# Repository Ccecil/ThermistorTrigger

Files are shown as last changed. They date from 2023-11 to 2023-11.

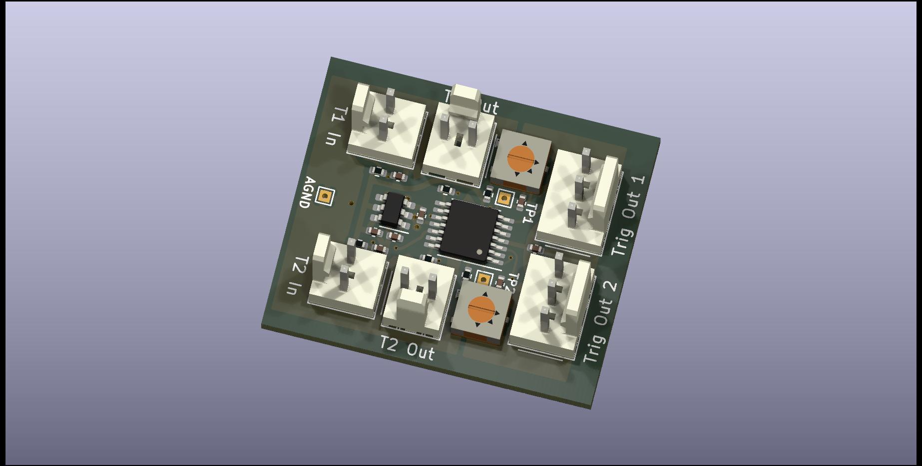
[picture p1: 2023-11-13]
ThermistorComparator.jpg

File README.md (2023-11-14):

# ThermistorTrigger

ThermistorComparator

Setpoint trigger designed to be a hardware failsafe for thermistor based temperature readings

This is designed to be a trigger board that can trigger other devices in the event of an overtemperature.  

Simply plug a standard thermistor into either input then the signal is buffered by an opamp and stabilized.  From there you can take the signal out and send it to your main control board as a temp sensor but it also drives into another opamp setpoint trigger which is set by the onboard potentiometer.  This allows you to set a trigger point in hardware that will drive the digital output of the setpoint trigger low if it exceeds the desired temp.

This is intended to go along with a couple of my other projects (Flambehub and Flambegate which are the devices which will kill the power in a "dumb" way requiring no MCU intervention) but this can also be used on a device such as a 3d printer (or other CNC device) to trigger a halt on the MCU if it is attached to the control board.

Available at: https://www.robosprout.com/product/thermistortrigger/

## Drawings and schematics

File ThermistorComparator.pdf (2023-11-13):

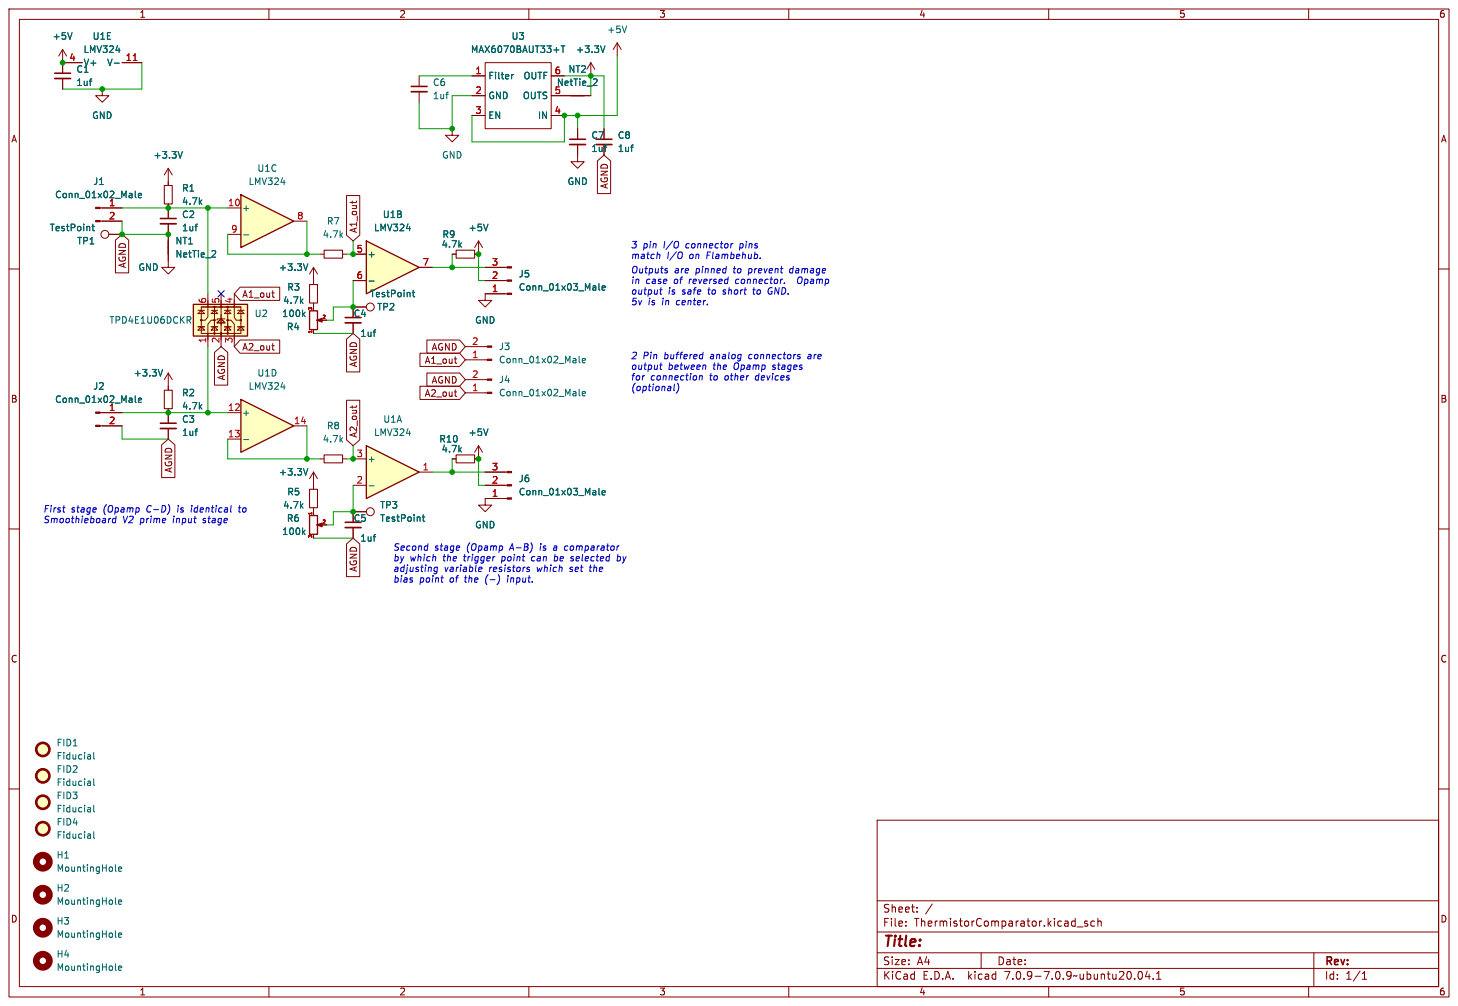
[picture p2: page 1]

output between the Opamp stages

FID3 Fiducial H1 MountingHole H2 MountingHole H4 MountingHole FID1 Fiducial

Id: 1/1 Title: File: ThermistorComparator.kicad_sch Sheet: / FID2 Fiducial

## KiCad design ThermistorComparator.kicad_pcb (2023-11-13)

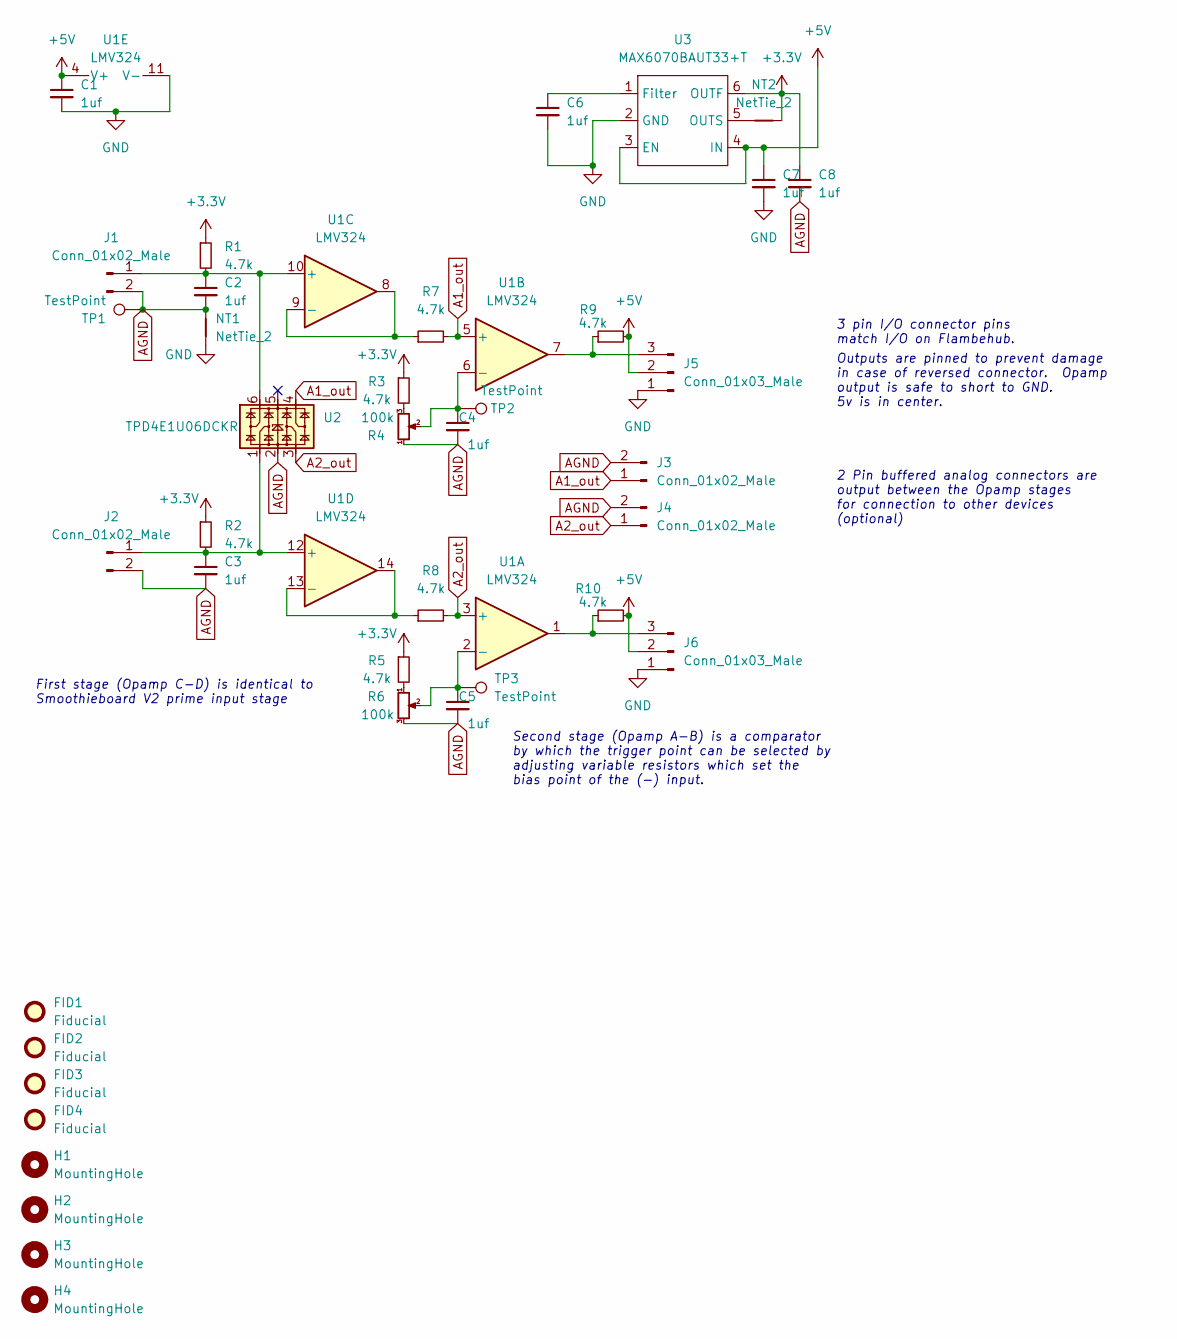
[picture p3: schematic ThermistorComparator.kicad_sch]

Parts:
C1, C2, C3, C4, C5, C6, C7, C8: 1uf; C_0402_1005Metric
FID1, FID2, FID3, FID4: Fiducial; Fiducial_0.5mm_Mask1mm
H1, H2, H3, H4: MountingHole; MountingHole_2.5mm
J1, J2, J3, J4: Conn_01x02_Male; Molex_KK-254_AE-6410-02A_1x02_P2.54mm_Vertical
J5, J6: Conn_01x03_Male; Molex_KK-254_AE-6410-03A_1x03_P2.54mm_Vertical
NT1, NT2: NetTie_2; NetTie-2_SMD_Pad0.5mm
R1, R2, R3, R5, R7, R8, R9, R10: 4.7k; R_0402_1005Metric
R4, R6: 100k; Potentiometer_Bourns_TC33X_Vertical
TP1, TP2, TP3: TestPoint; TestPoint_THTPad_1.0x1.0mm_Drill0.5mm
U1: LMV324; TSSOP-14_4.4x5mm_P0.65mm
U2: TPD4E1U06DCKR; SOT-363_SC-70-6
U3: MAX6070BAUT33+T; SOT-23-6

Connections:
+3.3V: C8.1, NT2.1, R1.1, R2.1, R3.1, R5.1, U3.6 (OUTF)
+5V: C1.1, C7.1, J5.2, J6.2, R9.2, R10.2, U1.4 (V+), U3.3 (EN), U3.4 (IN)
A1_out: J3.1, R7.2, U1.5 (+), U2.4
A2_out: J4.1, R8.2, U1.3 (+), U2.3
AGND: C2.2, C3.2, C4.2, C5.2, C8.2, J1.2, J2.2, J3.2, J4.2, NT1.2, R4.1, R6.3, TP1.1, U2.2
GND: C1.2, C6.2, C7.2, J5.1, J6.1, NT1.1, U1.11 (V-), U3.2 (GND)
unnamed: C2.1, J1.1, R1.2, U1.10 (+), U2.6
unnamed: C3.1, J2.1, R2.2, U1.12 (+), U2.1
unnamed: C4.1, R4.2, TP2.1, U1.6 (-)
unnamed: C5.1, R6.2, TP3.1, U1.2 (-)
unnamed: C6.1, U3.1 (Filter)
unnamed: J5.3, R9.1, U1.7
unnamed: J6.3, R10.1, U1.1
unnamed: NT2.2, U3.5 (OUTS)
unnamed: R3.2, R4.3
unnamed: R5.2, R6.1
unnamed: R7.1, U1.8, U1.9 (-)
unnamed: R8.1, U1.13 (-), U1.14

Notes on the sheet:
2 Pin buffered analog connectors are output between the Opamp stages for connection to other devices (optional)
First stage (Opamp C-D) is identical to Smoothieboard V2 prime input stage
Outputs are pinned to prevent damage in case of reversed connector. Opamp output is safe to short to GND. 5v is in center.
3 pin I/O connector pins match I/O on Flambehub.
Second stage (Opamp A-B) is a comparator by which the trigger point can be selected by adjusting variable resistors which set the bias point of the (-) input.

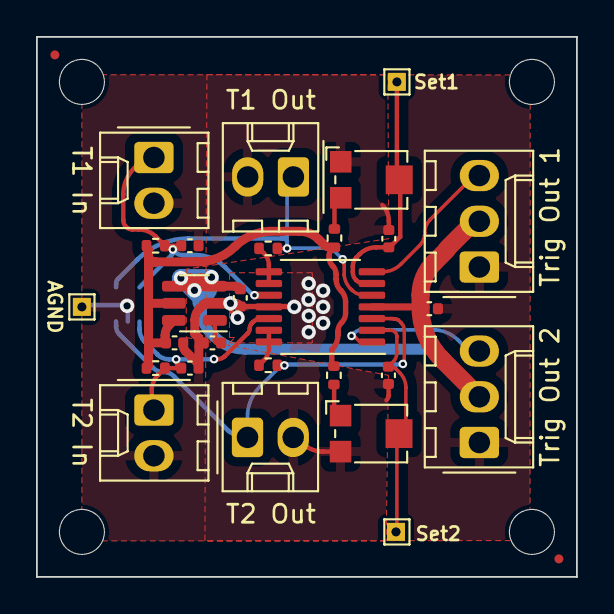
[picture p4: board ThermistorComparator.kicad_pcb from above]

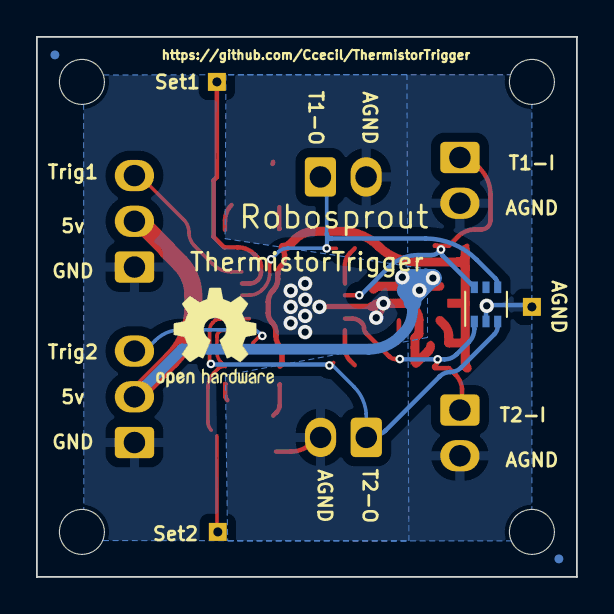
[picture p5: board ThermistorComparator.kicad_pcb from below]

Board: 2 copper layers, 30.0 x 30.0 mm, 38 parts (3 on the bottom side), 18 nets.

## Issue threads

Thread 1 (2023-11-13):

No method to detect open/shorted thermistor

Ccecil, 2023-11-13:
Next rev needs to mod the setpoint trigger to a window comparator or other similar setup so "out of range" can be better defined to trigger on a hardware fault such as detached or shorted thermistor.
